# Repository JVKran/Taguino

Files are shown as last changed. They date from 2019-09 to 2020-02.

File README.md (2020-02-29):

Showcase Video (https://youtu.be/YKAxMUS9iD8)
# Taguino
Lasertag-games are great fun! So why not make one? That's what this repository is for... This project consists of two devices;
- Weapons
- Gameleader

The Gameleader has the ability to set the gametime, enable powerups, show the scoreboard and type in names. Furthermore, it also
has an MP3 player to play suitable audio; lobby music while all players are signing up and fight music when the game starts.

The weapon can select the weapontype and firemode, or to display the scoreboard. Furthermore, also the health, amount of bullets and magazines and remaining time is printed on the display.

A brief showcase of the functioning of the weapon can be seen [here](https://youtu.be/YKAxMUS9iD8 "Lasergame Showcase"). The entire program is built upon [HWLIB](https://github.com/wovo/hwlib), [BMPTK](https://github.com/wovo/bmptk) and [RTOS](https://github.com/wovo/rtos).

The RTOS (Realtime Operating System) consists of tasks with priorities and concurrency mechanisms; pools, channels, flags, timers and clocks. All tasks are asynchronic; the used system uses cooperative multitasking.

### Gameleader
The gameleader is built with the following components:
- Keypad
- OlED (SSD1306)
- Rotary Encoder (EC11)
- NRF24L01+

The Gameleader dynamically assigns adresses to the weapons; when a weapon boots up, the Gameleader detects that and transmits an address to the weapon. After an address has been assigned the master concatenates the newly assigned address to an array. Now, when a player enters a name with the keypad, the first unoccupied weapon gets that name. That name is also used in the scoreboards. 

When the gameleader starts the game after setting the gametime, all players receive the message that define the start of a game and its duration. When a weapon disconnects, the game can just continue; the scoreboard remains.

### Weapon
The weapon has the following components:
- Ultrasonic distance sensor (HCSR04)
- RGB Led
- Infrared transmitter (TSUS5202) and receiver (VS1838B)
- OLED (SSD1306)
- Rotary Encoder (EC11)
- Microswitch
- Toggleswitch 
- NRF24L01+.

The ultrasonic distance sensor is used to determine wether or not a shotgun should kill a player. It should if the distance is shorter than 3 meters. Else it shouldn't.
The infrared transmitter and receiver are wired in such a way that the total distance is +-32 meters. That is, with pushing 525mA through a LED that's rated for 300mA and a very overthough receiver circuit.
The OLED and Rotary Encoder are used to display health, bullets, weapon, firemode, scoreboard and to switch between the several implemented windows.
The microswitch is used to fire a bullet and the toggleswitch is used to select the firemode. The NRF24L01+ is used as communication method between gameleader and weapons.

## Diagrams

### Master
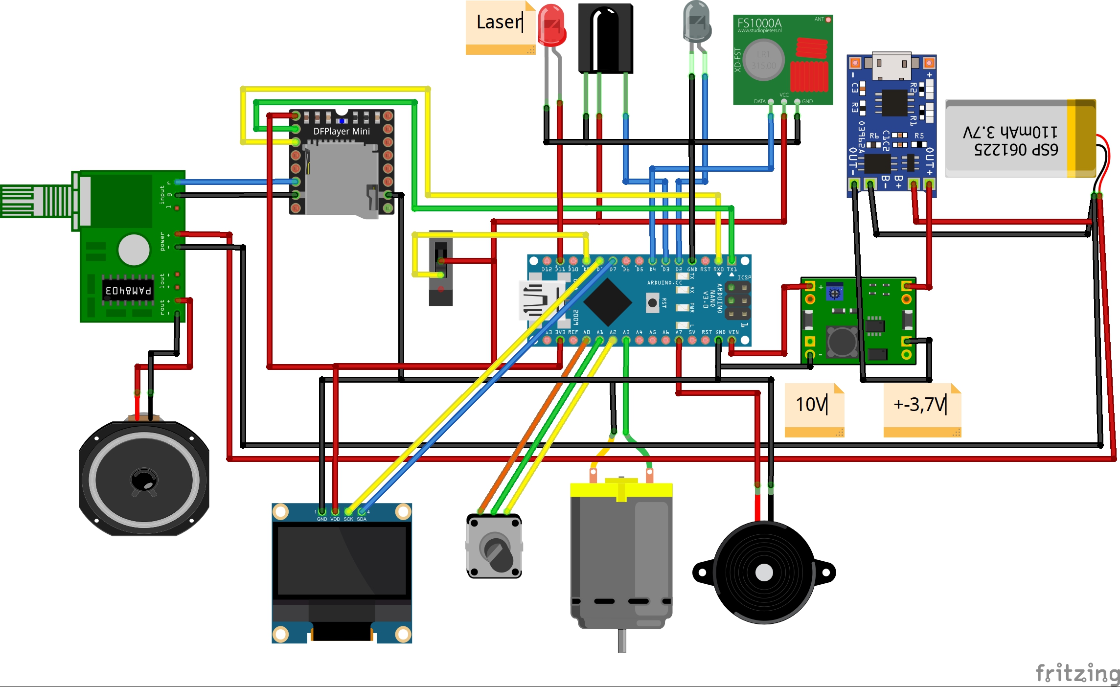
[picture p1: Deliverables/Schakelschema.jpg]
Master Schematic


### Weapon
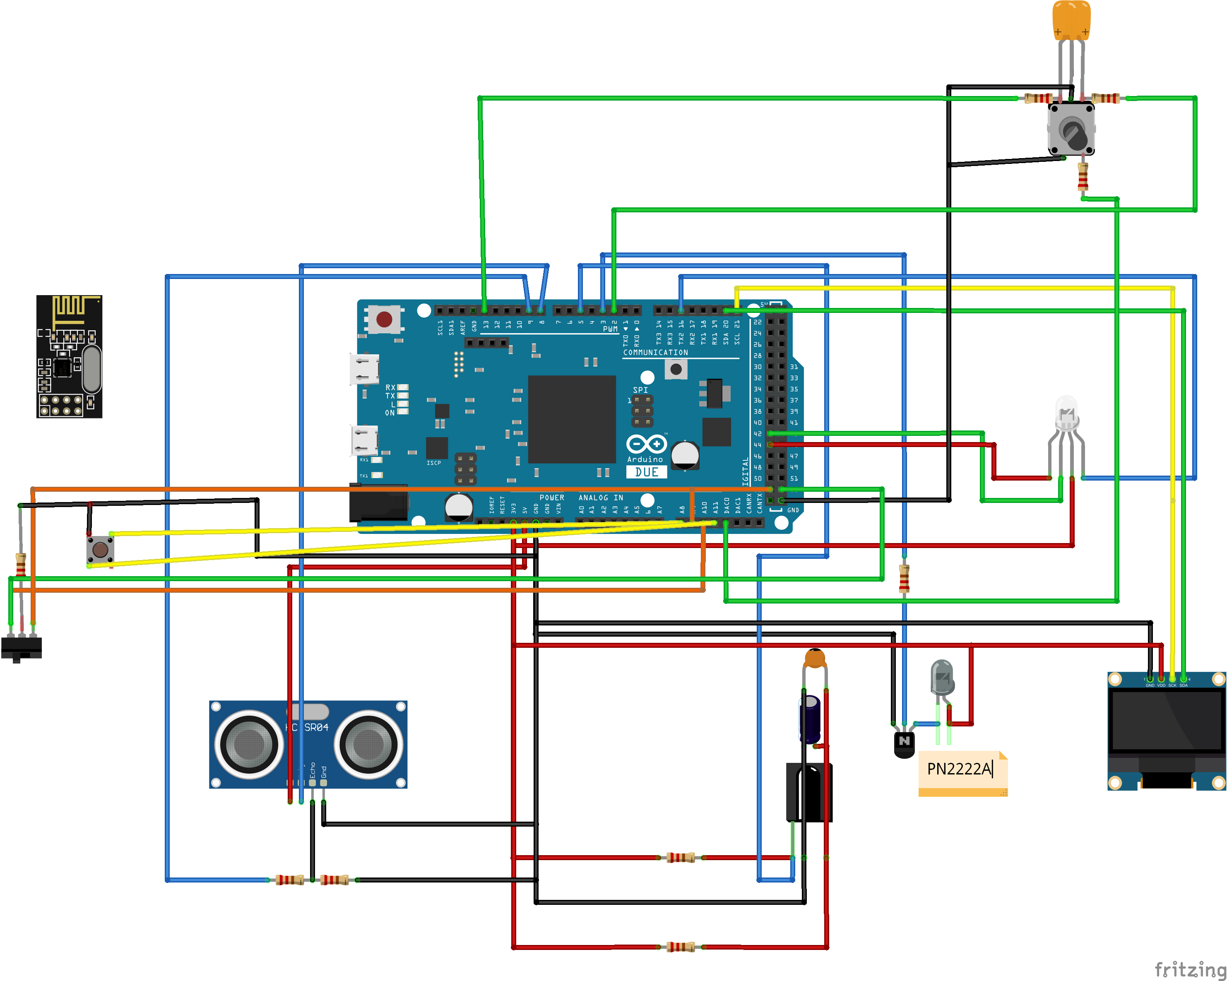
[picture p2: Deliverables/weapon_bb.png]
Weapon Schematic


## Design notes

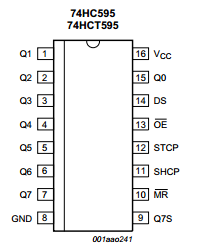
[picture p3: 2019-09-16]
hwlib/doxyfiles/images/hc595-pinout.png

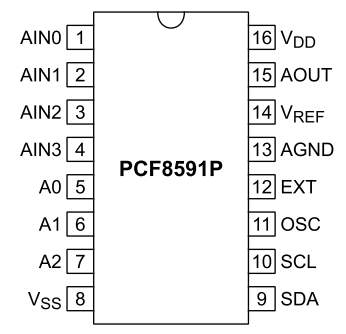
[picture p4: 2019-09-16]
hwlib/doxyfiles/images/pcf8591-pinout.png

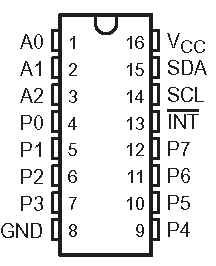
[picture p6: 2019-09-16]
hwlib/doxyfiles/images/pcf8574a-pinout.png

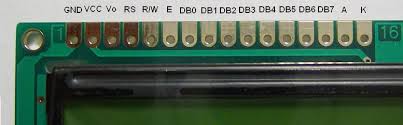
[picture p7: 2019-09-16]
hwlib/doxyfiles/images/hd44780-pinout.jpg

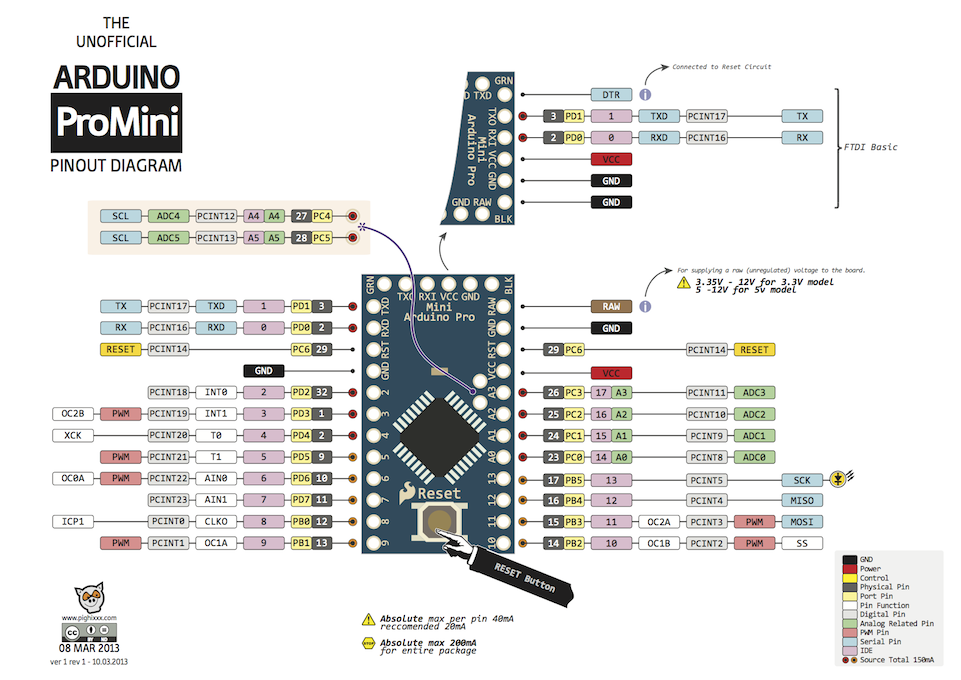
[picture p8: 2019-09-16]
hwlib/doxyfiles/images/mini-pro-pinout.png

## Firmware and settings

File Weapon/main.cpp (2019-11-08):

#include "hwlib.hpp"
#include "entities.hpp"
#include "interface.hpp"
#include "input.hpp"
#include "weapon.hpp"
#include "game.hpp"
#include "display.hpp"
#include <array>

int main( void ){	
   hwlib::wait_ms( 500 );

   auto scl    = hwlib::target::pin_oc(hwlib::target::pins::scl);
   auto sda    = hwlib::target::pin_oc(hwlib::target::pins::sda);

   auto i2cBus = hwlib::i2c_bus_bit_banged_scl_sda(scl, sda);
   auto oled   = hwlib::glcd_oled(i2cBus);

   auto scoreFont      = hwlib::font_default_8x8();
   auto scoreWindow    = hwlib::window_part(oled, hwlib::xy(88, 9), hwlib::xy(128, 17));
   auto scoreBoardWindow    = hwlib::window_part(oled, hwlib::xy(0, 0), hwlib::xy(128, 64));
   auto scoreTerminal  = hwlib::terminal_from( scoreWindow, scoreFont );
   auto scoreBoardTerminal = hwlib::terminal_from( scoreBoardWindow, scoreFont );

   auto sclk = hwlib::target::pin_out( hwlib::target::pins::d24 );
   auto mosi = hwlib::target::pin_out( hwlib::target::pins::d26 );
   auto miso = hwlib::target::pin_in( hwlib::target::pins::d28 );
   auto csn  = hwlib::target::pin_out( hwlib::target::pins::d30 );
   auto ce   = hwlib::target::pin_out( hwlib::target::pins::d32 );

   auto spiBus = hwlib::spi_bus_bit_banged_sclk_mosi_miso(sclk, mosi, miso);

   constexpr auto xCoordinates = lookup< int, 360>(scaled_sine_from_degrees);
   constexpr auto yCoordinates = lookup< int, 360>(scaled_cosine_from_degrees);

   //This one is device specific
   const uint8_t weaponNumber = 1;

   const long long int infraredPollPeriod = 200;
   const long long int infraredTransmitPeriod = 100;
   const long long int inputPollPeriod = 100'000;
   const long long int radioPollPeriod = 100'000;
   
   playerData player = playerData();
   weaponData weapon = weaponData(2);
   inputHandler handler = inputHandler(inputPollPeriod);                   //Period to poll register with buttonstates
   display Display = display(oled, xCoordinates, yCoordinates, scoreWindow, scoreTerminal, scoreBoardTerminal, player);
   runGame game = runGame(Display, player, spiBus, radioPollPeriod, handler, weaponNumber);
   infraredDecoder decoder = infraredDecoder(game);
   infraredReceiver receiver = infraredReceiver(decoder, infraredPollPeriod);
   infraredTransmitter Transmitter = infraredTransmitter(infraredTransmitPeriod);
   weaponManager gunManager = weaponManager(Display, handler, player, Transmitter);
   interfaceManager interface = interfaceManager(Display, handler, gunManager);

   hwlib::cout << "Weapon Started!" << hwlib::endl;
   rtos::run();
}

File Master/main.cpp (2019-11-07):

#include "hwlib.hpp"
#include "entities.hpp"
#include "scoreboard.hpp"
#include "input.hpp"
#include "game.hpp"
#include "display.hpp"
#include "interface.hpp"
#include "signup.hpp"
#include "scoreboard.hpp"
#include <array>

int main( void ){	
   hwlib::wait_ms( 500 );

   auto scl    = hwlib::target::pin_oc(hwlib::target::pins::scl);
   auto sda    = hwlib::target::pin_oc(hwlib::target::pins::sda);
   auto i2cBus = hwlib::i2c_bus_bit_banged_scl_sda(scl, sda);
   auto oled   = hwlib::glcd_oled(i2cBus);

   constexpr auto xCoordinates = lookup< int, 360>(scaled_sine_from_degrees);
   constexpr auto yCoordinates = lookup< int, 360>(scaled_cosine_from_degrees);
   auto scoreFont      = hwlib::font_default_8x8();
   auto scoreWindow    = hwlib::window_part(oled, hwlib::xy(88, 9), hwlib::xy(128, 17));
   auto scoreTerminal  = hwlib::terminal_from( scoreWindow, scoreFont );
   auto nameWindow     = hwlib::window_part(oled, hwlib::xy(0, 0), hwlib::xy(100, 10));
   auto nameTerminal   = hwlib::terminal_from( nameWindow, scoreFont);

   auto sclk = hwlib::target::pin_out( hwlib::target::pins::d9 );
   auto mosi = hwlib::target::pin_out( hwlib::target::pins::d12 );
   auto miso = hwlib::target::pin_in( hwlib::target::pins::d7 );
   auto csn  = hwlib::target::pin_out( hwlib::target::pins::d11 );
   auto ce   = hwlib::target::pin_out( hwlib::target::pins::d10 );

   auto spiBus = hwlib::spi_bus_bit_banged_sclk_mosi_miso(sclk, mosi, miso);

   const long long int radioPollPeriod = 10'000;
   const uint8_t addressToListenTo = 0;
   const long long int inputPollPeriod = 100'000;

   NRF24 radio = NRF24(spiBus, ce, csn, radioPollPeriod, addressToListenTo);
   display Display = display(oled, xCoordinates, yCoordinates, scoreWindow, scoreTerminal, nameTerminal);
   scoreboard bord;

   game gameRunner = game(Display, radio,bord);
   inputHandler handler = inputHandler(inputPollPeriod);
   signUp signer = signUp(radio,handler,gameRunner, bord, Display); 
   interfaceManager interface = interfaceManager(Display, handler, signer, gameRunner);
   radio.addListener(&signer);
   radio.addListener(&gameRunner);

   hwlib::cout << "Master Started!" << hwlib::endl;
   rtos::run();
}

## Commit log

2019-09-04 Created Diagrams
    Created Diagrams to make sure no parts are missed for the order.
    [Schakelschema.fzz]
2019-09-04 Cleaned Up
    [Schakelschema.fzz]
2019-09-11 Uploaded wiring-diagrams
    [Grenade.fzz, Master.fzz, MasterHelper.fzz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]
2019-09-30 Rotary encoder and EEPROM added
2019-10-15 Improved Rotary Encoder for Concurrent Use
2019-10-28 added RGB Led
2019-10-28 Working inputHandler with encoderListener and buttonListener
2019-10-28 added PWM for led
2019-10-28 added pwm for 3 colors
2019-10-28 added documentation and cleaned up code for RGB LED
2019-10-28 cleaned up code for RGB led
2019-10-29 added code for button interrupt
2019-10-29 fixed buttoninterrupt
2019-10-29 changed the way buttoninterrupter works
2019-10-29 Taskified Button
2019-10-29 Merged led with task
2019-10-30 added extra button
2019-10-30 combined encoder with buttons cleaned up code
2019-10-31 added more buttons
2019-10-31 Display 90% complete. Only powerups are missing
    [main.cpp]
2019-10-31 Added 2 powerups
2019-10-31 2 buttons raising edge
2019-10-31 Added modulo 2 condition
    To prevent odd positions.
    [interface.cpp]
2019-10-31 Buttons fully working
2019-11-01 Fixed Infrared communiation in task
    [main.cpp]
2019-11-01 Removed couts for the drawing issue
    [main.cpp]
2019-11-03 Fixed some OLED problems
    [game.cpp, game.hpp, main.cpp]
2019-11-05 Added bubblesort and swap to Master
    [game.cpp, game.hpp]
2019-11-05 Removed Trace
2019-11-05 Bullets and amount of mags now change to the correct amount of the weapon
    [game.cpp, game.hpp, interface.cpp]
2019-11-06 Added task, not working yet
    [game.cpp, game.hpp, interface.cpp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]
2019-11-06 Fixed rgb led formula
    [game.cpp, game.hpp]
2019-11-06 fixed lots of stuff
    [KY040.cpp, game.cpp, game.hpp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]
2019-11-06 fixed alot, added scoreboard
    [game.cpp, game.hpp, main.cpp]
2019-11-08 Finished Lasergame
2020-02-29 Made schematics
    [weapon.fzz]
